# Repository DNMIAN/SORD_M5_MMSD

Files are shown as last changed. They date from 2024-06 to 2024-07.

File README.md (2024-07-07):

SORD m5 メモリマッパー (+SD)  
  
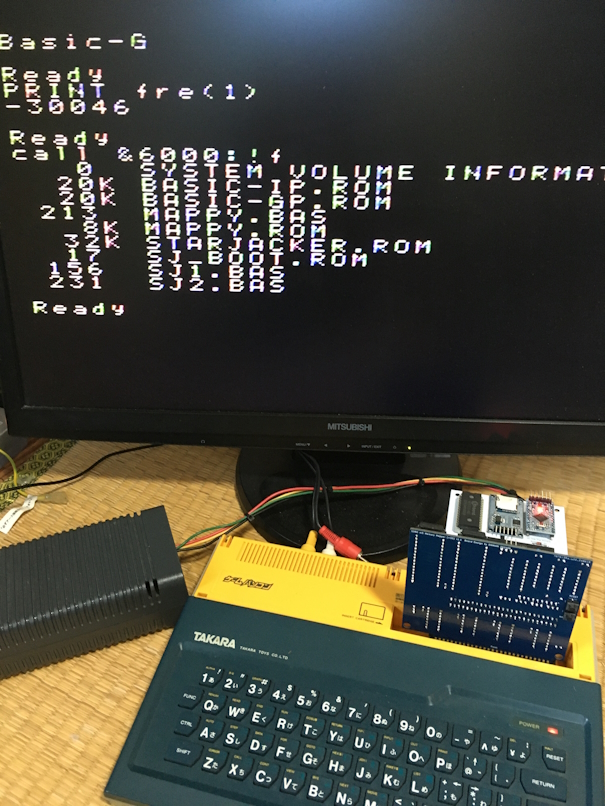
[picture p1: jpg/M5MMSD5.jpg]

  
注意  
・m5 Jr.に挿せるかは検証できていません。  
・純正電源で動作するかは確認できていません。（外部電源入力は可能）  

1. 概要  
  
本ハードウェアは、SORD m5（および互換PC）に、ROMを512Kバイト、RAMを512Kバイトを拡張する装置です。  
各メモリは16Kバイト単位のセグメントに分割され、ROM32ページ、RAM32ページとして管理します。  
CPUのメモリ空間64Kバイトを16Kバイト単位で4分割し、CPU空間0～3とします。  
それぞれのCPU空間について、任意のページを対応させることができます。  
（いわゆるMSXのメモリマッパーです）  
  
また、yanatakaさんのMSX_SD ver1.6 (https://github.com/yanataka60/MSX_SD) を使用することを目的とした、  
MSXカートリッジI/F（以降、MSX-I/F)を備えています。  

2. 製作について  
  
組み立て以外に、EPROM書き込みが必要です。  
  
また、MSX_SDのドキュメントも必ず読みましょう。  
MSX_SDはArduinoスケッチ書き込みが必要です。  

3. 基板、部品リスト  
  
回路図とガーバーデータはKiCad7.0で作成しています。  
  
動作確認をした部品リストを、以下に示します。  
74HCをLSにした場合、動作しない可能性があります。  
  
U1,U2 : 74LS670 x2  
U3 : 74HC244  
U4 : HM628512ALP-7  
U5 : 512Kx8bit以下 DIP32 EPROM（M27C4001-10F1,W27C010-70で確認）  
U6 : 74HC20  
U7 : 74HC00  
U8 : 74HC30  
U9 : 74HC139  
CON : カードエッジコネクタ 2x25P 2.54mm  
C1～C9 : 積層セラミックコンデンサ 50V 0.1uF x9  
C10 : 電解コンデンサ 16V 100uF  
RN1 : 集合抵抗 6素子 10kΩ  
R1 : 抵抗 10kΩ  
SW1,SW2 : タクトスイッチ TVDP17-050B-D x2  
EX5V : ピンヘッダ 1x2P 2.54mm  
EX12V,GND : ピンヘッダ 1x3P 2.54mm  
EXIO,A4～A7 : ピンヘッダ 1x3P 2.54mm x5  
ICソケット : DIP32（U5用）  
ジャンパーピン : 2.54mm（EX5V,EXIO,A4～A7用） x6  
  
MSX_SD ver1.6 : 基板は公開されているガーバーから作成  
U1 : 74HC02  
U2 : 74HC138  
U3 : W27C512-45Z（後半32KBを使用） ※MSXで動作確認時に使用  
U4 : uPD8255AC-5  
U5 : Arduino Pro Mini 328 5V 16MHz（ピンヘッダ付属）  
J3 : MicroSD Card Adapter  
C1～C4 : 積層セラミックコンデンサ 50V 0.1uF x4  
C5 : 電解コンデンサ 16V 100uF  
D1 : ダイオード 1N4148  
ピンヘッダ : 1x2P 2.54mm（Arduino A4,A5用）  
ICソケット : DIP28（U3用）  
microSDカード : 2GB  
  
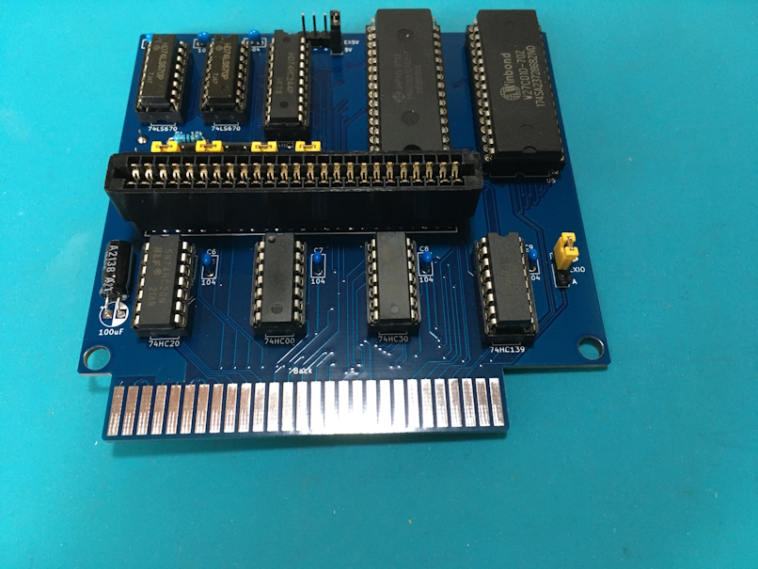
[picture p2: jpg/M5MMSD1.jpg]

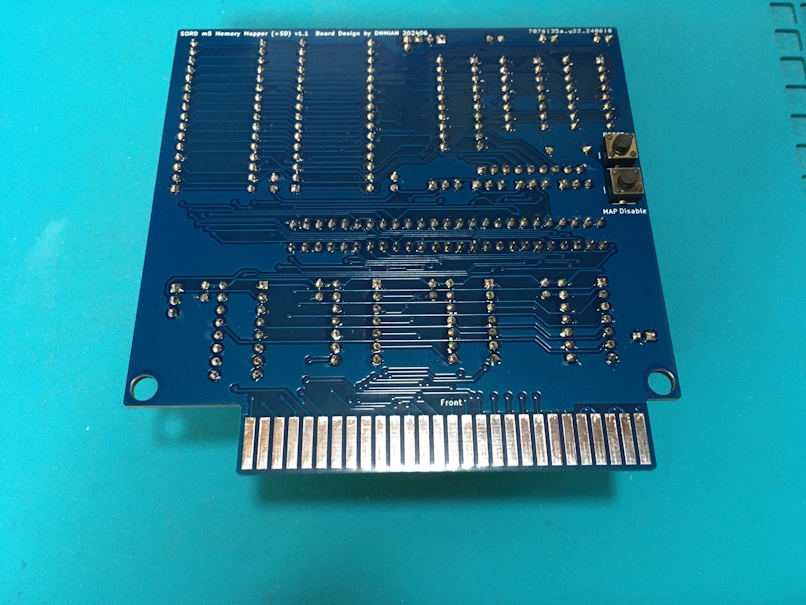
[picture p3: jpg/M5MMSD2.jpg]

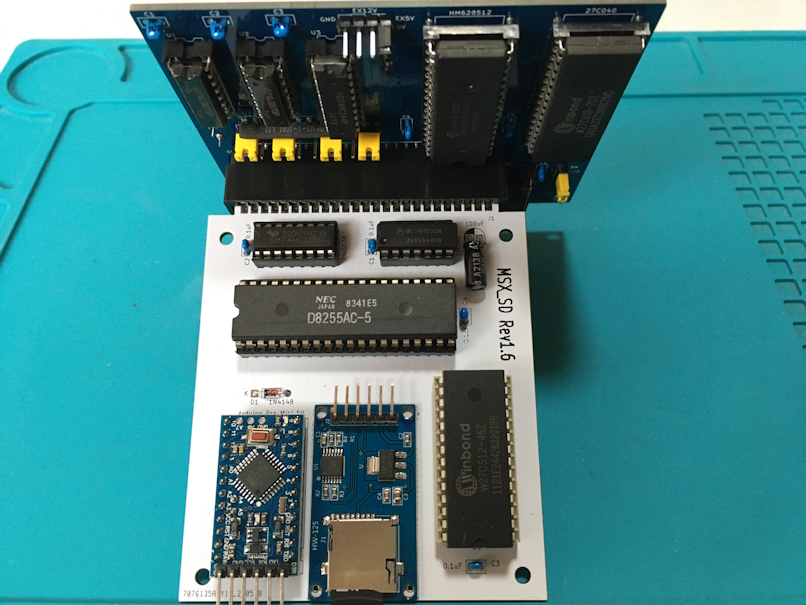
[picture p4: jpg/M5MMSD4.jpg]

  
4. ジャンパー設定  
  
基板上にあるジャンパーついての説明です。  
EXIO,A4～A7ジャンパーは●側をショート、EX5V-5Vもショートしてください。（計6箇所）  
  
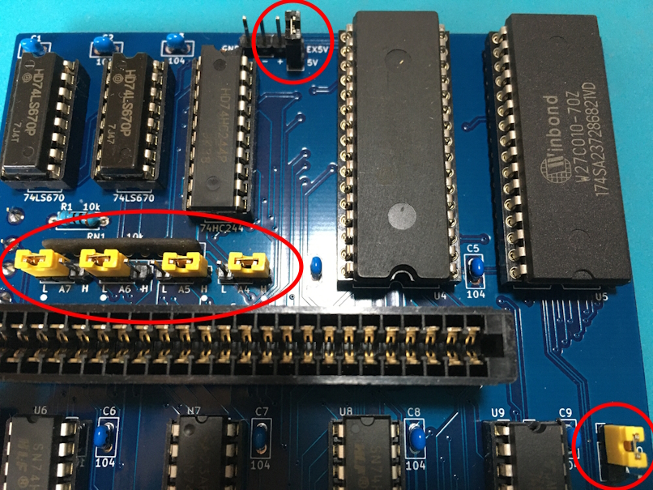
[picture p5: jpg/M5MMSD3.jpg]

  
EXIO : MSX-I/Fの/IORQを、選択（/EXIOA or /EXIOB）します。m5は7xHを使用するので/EXIOBを設定します。  
A4～A7 : アドレスバスA4～A7を選択します（H or L）、これは使用するMSXカートリッジの仕様に強制的に合わせるものです。MSX_SDのIOポートは、38H～3BHなので、A7L, A6L, A5H, A4Hを設定します。  
EX5V : MSX-I/Fの5V供給を選択します。5Vとショートでm5から供給です。外部供給する場合、ジャンパーを外して、EX5V側へ5Vを接続します。  
5V : m5供給の5Vです。  
EX12V : MSX_SDでは使用しません。ジャンパーはしないでください。MSX-I/Fに±12Vが必要な場合は、それぞれのピンから外部供給できます。  
GND : 外部供給時のGNDを接続します。  
  
m5カートリッジバスの/IORQは、6xHアクセスで/EXIOA、7xHアクセスで/EXIOBがアサートされます。  
アドレスをそのままMSX-I/Fに出力した場合、MSXカートリッジは60H～7FHまでのIO機器しか使用できません。  
MSX_SDは38H～3BHを使用します。  
上位4bitを3(0011b)に固定することで、m5での78Hアクセスを、MSX-I/Fでは38Hアクセスに見せかけます。  
  
この仕組みを使用して、他のIOカートリッジを動作させることができるかもしれません。  
（MSX-MUSICの7CH,7DHを、6CH,6DHでアクセスするなど（メモリマッパー7CH～7FHとの競合回避））  

5. Arduinoスケッチについて  
  
MSXM5_SD.inoファイルを使用してください。  
MSX_SD.inoにm5処理を追加しているので、そのままMSXでも動作します。  

6. ROMについて  
  
メモリマッパーに実装するROMは、4Mbit(M27C4001, AM27C040, W27E040など), 2Mbit, 1Mbit等の  
32ピンDIPパッケージが使用可能です。（容量が少ない場合は、サイズ毎にページ内容がミラーされます）  
  
MSX_SD上のROMは使用しません。m5のみで使用なら実装する必要はありません。  

7. マッパーセグメントの切替について  
  
CPU空間0～3の対応は、マッパーセグメント選択レジスタによって決められます。  
マッパーセグメント選択レジスタは、I/Oアドレスの7CH番地から7FH番地までの4バイトです。  
レジスタ値は00H～1FHでROM, 20H～3FHでRAMを選択します。  
  
電源投入後の初期値は、全レジスタ値ともに不定のため、マッパーセグメント選択レジスタに書き込むまでは  
強制的に無効（全レジスタ値=00H扱い）する機能を実装しています。  
このため、ROMの0ページに適切な初期化処理を配置するのが良いでしょう。  
  
また、m5のハードウェア制約により、ページ0の0000H～1FFFHはIPLROM、ページ1の7000～7FFFHは内蔵RAMに固定されます。  
  
m5のブートシーケンスは、詳細は書きませんが、起動時に2000Hから 02 xx yy zz vv のコードがあれば、vvzzを呼び出します。  
vvzzから復帰後、yyxxを呼び出しますが、復帰しないプログラムならyyxxを設定する必要はありません。  
  
よって、ページ0の2000Hからマッパー初期化処理を配置することになります。  
しかし、実行中のコードがあるページを切り替えると、コードがすり替わってしまい想定外の動作となるため、  
別ページで切替処理を実行する必要があります。  
  
電源投入時は全ページ0となっているため、2000Hからのコードは、6000H, A000H, E000Hでもアクセスすることができます。  
これを利用して、例えばAxxxHへ分岐して、そこでページ0のマッパー設定を行うと良いように見えますが、これは間違いです。  
  
前述にある「強制的に無効」する機能は、マッパーレジスタに書き込みを行うことで、解除されます。  
よって、解除された瞬間に、不定レジスタ値でページが切り替わってしまう可能性があります。  
これを回避するため、最初はページ0のレジスタ値を0に更新します。  
その後、ページ1,2,3のレジスタ値についても適切に更新しておくのが良いでしょう。  
  
なお、「強制的に無効」する機能は、リセットでは有効になりません。  
マッパーレジスタ値も、リセットでは変化しません。  
「強制的に無効」する機能を有効にしたい（＝ページ0から実行）場合は、ボード上の「MAP Disable」ボタンを一度押してください。  
押した瞬間に動作しますので、その後、RESETボタンも押して再起動するのが良いでしょう。  
電源投入時は、（ほぼ）有効になると思いますが、起動しない場合は「MAP Disable」＋「RESET」を試して見ましょう。  

8. MSX_SD上のSDアクセスについて  
  
ハード的な仕様はオリジナルのままです。  
MSX_SDで使うSDカードは8GB以下が望ましいとの記載がありました。  
  
SDアクセス（＋マッパー切替）については、BASIC-I,BASIC-G用の簡易プログラムを作りました。  
（yanatakaさんのPC-8001_SDを参考にしています。）  
使い方は、ソースコードの先頭にあるコメントを参照してください。  
なお、SD読み書き時のエラーチェックはしていません、容量不足などには注意ください。  

9. プログラムとか  
  
MSXM5_SD.ino : MSX_SDのArduinoスケッチ  
  
EXT_ROM_M5.s : SDアクセス（＋マッパー切替） ソースコード  
EXT_ROM_M5_G.ROM : BASIC-G用のRAWファイル（6000H～6FFFHへ実装用）  
EXT_ROM_M5_I.ROM : BASIC-I用のRAWファイル（6000H～6FFFHへ実装用）  
  
BOOT_SAMPLE.s : ブート サンプルソースコード  
BOOT_SAMPLE.rom : RAWファイル（2000H～2FFFHへ実装用）  
  
BOOT_SEL.s : ブートセレクターソースコード  
BOOT_SEL.rom : RAWファイル（2000H～2FFFHへ実装用）  

10. ライセンスとか  
  
This project is licensed under the MIT License, see the LICENSE.txt file for details

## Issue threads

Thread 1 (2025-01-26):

how to launch game ?

hpx1984, 2025-01-26:
hi Sir

thx your great project , i love it and like to build one
now im already completed MSX_SD and it can working on MSX

based to review the details of this project im still not know how to launch game
i saw from video many times
my question
1. what format for the M5 ROM what can be launch ? .rom or .bas?(I find some M5 ROM but it is .bin format )
2. what file need to stock in sd card ?and how to place these file?
3. what command for launch game ?

for the PCB
seems move the Connector to another side then not need to remove the M5 Card cover for use MMSD

DNMIAN, 2025-01-26:
First, you need a BOOT ROM to insert into U5.
If you use BOOT_SEL.rom, you can load the file on the SD and start it.
Since the U5 ROM runs from 2000H, leave 0000 to 1FFFH blank and place BOOT_SEL.rom from 2000H.
The file to be placed in the SD is a binary that can be executed from 2000H. This is a raw dump of a ROM cartridge.
Also, regarding BASIC programs, I don't think you can use anything other than those saved with M5MMSD.
When loading and saving to SD in BASIC, the corresponding EXT_ROM_M5 must be placed in 6000H.
In the case of BASIC-G, it is 16KB, just concatenate EXT_ROM_M5_G.rom after the ROM image and make it into one file.
In the case of BASIC-I, it is 8KB, so concatenate an 8KB blank at the end, and concatenate EXT_ROM_M5_I.rom after that to make one file.
Thank you.

hpx1984, 2025-01-26:
Many thx your explained Sir DNMIAN

Now i got to know some details about M5-MMSD ,but im new guy on M5 and BASIC, so still some information that i can't understand at this moment
I think need to build and complete one M5-MMSD board then can study and try how to use it
I will go ahead to order M5-MMSD PCB and Elec components

So might need more help from you later

DNMIAN, 2025-01-27:
I hope that you can complete it.
Please let me know if you have any questions.
Good luck.

DNMIAN, 2025-02-24:
Thank you for assembling.

M5-MMSD Board:
Write the M5-MMSD/Z80/Work/BOOT_SEL_0000H.rom to W27C010-70.
This is BOOT_SEL.rom with 2kbytes of free space inserted at the beginning.

MSX-SD board ROM chip
Since this ROM is not used, a program for MSX is fine.

The boot selector should now start.

Please try it.

hpx1984, 2025-02-24:
last week end i already trial to use BOOT_SEL.rom to do some modification by HxD tool to insert FF to 0x0000-0x1FFF and then move the original code start at 0x2000 and then repack the ROM to program into 27c010 but got black screen and click some key can get key tone

Now im just trial to use Work/BOOT_SEL_0000H.rom to W27C010-70 and got same status as above

hpx1984, 2025-02-24:
what files need to put into TF card ?
is it the problem why i got black screen ?
because no correct files put into TF card

DNMIAN, 2025-02-25:
Just to confirm, it's hard to see the image, but is the EXIO jumper set to B?

If it stops at a black screen, I think it's because it hasn't started or the MSX-SD can't be initialized.
First, you should see a list of files. You can check it with the TF card of MSX-SD. The file can be anything.

First, let's check if it works on its own.
Don't have BASIC-I,G or game ROM image?
Create an empty 8kbytes file and concatenate the BASIC or game ROM image to the back.
(ROM image start is 0x2000)
Write it to W27C010 and boot with it.
Do not insert MSX-SD.

DNMIAN, 2025-02-25:
sorry. I'm posting a mistake. Please wait while I correct it.

DNMIAN, 2025-02-25:
Write the M5-MMSD/Z80/Work/TEST.ROM to W27C010-70.

hpx1984, 2025-02-26:
HI Sir

TEST.ROM and insert MSX-SD without SD card=black screen
TEST.ROM without MSX-SD=black screen

DNMIAN, 2025-02-26:
Write the M5-MMSD/Z80/Work/BOOT_TEST.ROM to W27C010-70.
There is no need to insert MSX-SD.

If nothing is displayed on the screen even after this, can you run it using an external power supply?

Remove the EX5V-5V jumper and connect an external power supply of about 5V1A between EX5V and GND.

DNMIAN, 2025-02-26:
If the screen does not appear, try pressing the "MAP Disable" + "RESET" buttons while the power is on.

hpx1984, 2025-02-28:
Hi Sir

BOOT_TEST.ROM to W27C010-70=black screen
Remove the EX5V-5V jumper and connect an external power supply of about 5V1A between EX5V and GND=black screen
pressing the "MAP Disable" + "RESET" buttons while the power is on and then release these two bottons=black screen

hpx1984, 2025-02-28:
Hi Sir

BOOT_TEST.ROM to W27C010-70=black screen
Remove the EX5V-5V jumper and connect an external power supply of about 5V1A between EX5V and GND=black screen
pressing the "MAP Disable" + "RESET" buttons while the power is on and then release these two bottons=black screen

DNMIAN, 2025-03-02:
Regular BASIC and game cartridges work, right?
Also, you haven't modified the m5 body, right?
If this doesn't work, all I can think of is that the IC isn't working or there's a wiring mistake somewhere.

I'm sorry that I can't seem to solve it.

Operation result with BOOT_TEST.ROM
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

hpx1984, 2025-03-02:
Hi Sir

the original BASIC-G and Game cartridges can working
i never modify my M5

i bought 5 sets IC before , let me try to replace them and double check the soldering status to looking if any mistake

hpx1984, 2025-03-08:
Hi Sir

Could you show which chip you are use for reference ? then i will try to find the same one to try again

This is what chip i used

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

DNMIAN, 2025-03-09:
The one I'm using is as shown in the picture, the RAM is remarked (it disappeared when I rubbed it, it's fake). I think it was the same as the one in the second picture.

Since it is a socket, operation can be checked with minimal implementation.
Remove HC30, LS670x2, and HM628512, and set W27C010 to BOOT_TEST.ROM.
Now when you boot up, BOOT TEST will be displayed. If the screen goes blank immediately and a relay sound is heard, press MAPdisable and then RESET.
Now BOOT TEST will be displayed.
First, let's aim to get this to work.

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

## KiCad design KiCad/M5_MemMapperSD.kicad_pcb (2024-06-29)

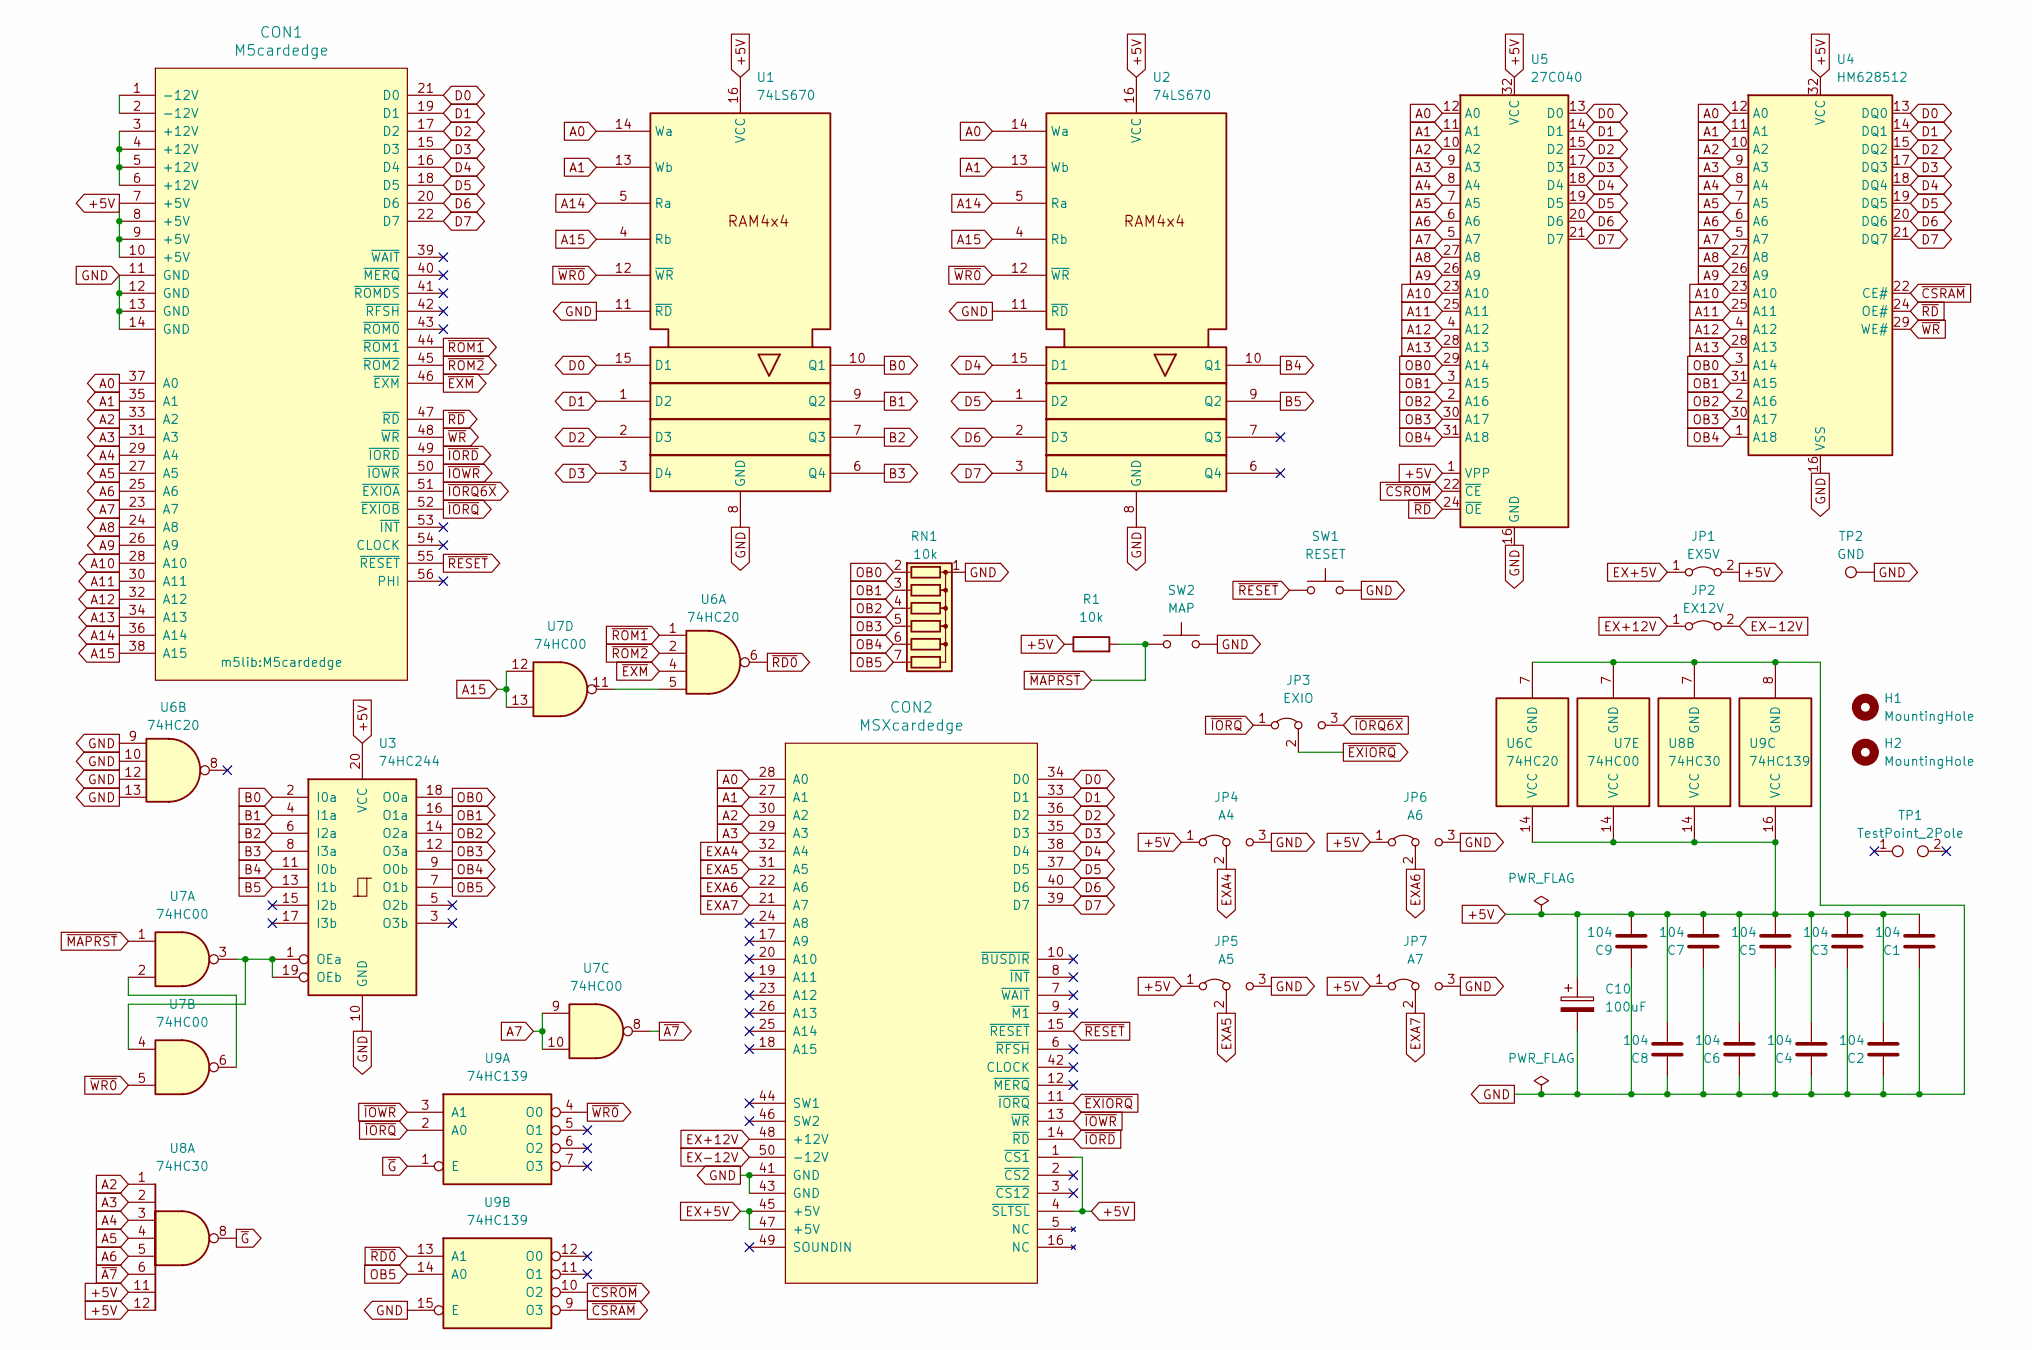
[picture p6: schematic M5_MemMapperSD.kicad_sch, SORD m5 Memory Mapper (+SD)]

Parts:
C1, C2, C3, C4, C5, C6, C7, C8, C9: 104; C_Disc_D5.0mm_W2.5mm_P2.50mm
C10: 100uF; CP_Radial_D5.0mm_P2.50mm
CON1: M5cardedge
CON2: MSXcardedge; 50_pin_edge_female
H1, H2: MountingHole; MountingHole_4.5mm
JP1: EX5V; PinHeader_1x02_P2.54mm_Vertical
JP2: EX12V; PinHeader_1x02_P2.54mm_Vertical
JP3: EXIO; PinHeader_1x03_P2.54mm_Vertical
JP4: A4; PinHeader_1x03_P2.54mm_Vertical
JP5: A5; PinHeader_1x03_P2.54mm_Vertical
JP6: A6; PinHeader_1x03_P2.54mm_Vertical
JP7: A7; PinHeader_1x03_P2.54mm_Vertical
R1: 10k; R_Axial_DIN0207_L6.3mm_D2.5mm_P7.62mm_Horizontal
RN1: 10k; R_Array_SIP7
SW1: RESET; SW_PUSH_6mm_H4.3mm_2pin
SW2: MAP; SW_PUSH_6mm_H4.3mm_2pin
TP1: TestPoint_2Pole; C_Disc_D5.0mm_W2.5mm_P2.50mm
TP2: GND; TestPoint_THTPad_2.0x2.0mm_Drill1.0mm
U1, U2: 74LS670; DIP-16_W7.62mm
U3: 74HC244; DIP-20_W7.62mm
U4: HM628512; DIP-32_W15.24mm
U5: 27C040; DIP-32_W15.24mm
U6: 74HC20; DIP-14_W7.62mm
U7: 74HC00; DIP-14_W7.62mm
U8: 74HC30; DIP-14_W7.62mm
U9: 74HC139; DIP-16_W7.62mm

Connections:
+5V: C1.2, C2.2, C3.2, C4.2, C5.2, C6.2, C7.2, C8.2, C9.2, C10.1, CON1.7 (+5V), CON1.8 (+5V), CON1.9 (+5V), CON1.10 (+5V), CON2.1 (~CS1), CON2.4 (~SLTSL), JP1.2 (B), JP4.1 (A), JP5.1 (A), JP6.1 (A), JP7.1 (A), R1.1, U1.16 (VCC), U2.16 (VCC), U3.20 (VCC), U4.32 (VCC), U5.1 (VPP), U5.32 (VCC), U6.14 (VCC), U7.14 (VCC), U8.11, U8.12, U8.14 (VCC), U9.16 (VCC)
A0: CON1.37 (A0), CON2.28 (A0), U1.14 (Wa), U2.14 (Wa), U4.12 (A0), U5.12 (A0)
A1: CON1.35 (A1), CON2.27 (A1), U1.13 (Wb), U2.13 (Wb), U4.11 (A1), U5.11 (A1)
A2: CON1.33 (A2), CON2.30 (A2), U4.10 (A2), U5.10 (A2), U8.1
A3: CON1.31 (A3), CON2.29 (A3), U4.9 (A3), U5.9 (A3), U8.2
A4: CON1.29 (A4), U4.8 (A4), U5.8 (A4), U8.3
A5: CON1.27 (A5), U4.7 (A5), U5.7 (A5), U8.4
A6: CON1.25 (A6), U4.6 (A6), U5.6 (A6), U8.5
A7: CON1.23 (A7), U4.5 (A7), U5.5 (A7), U7.9, U7.10
A8: CON1.24 (A8), U4.27 (A8), U5.27 (A8)
A9: CON1.26 (A9), U4.26 (A9), U5.26 (A9)
A10: CON1.28 (A10), U4.23 (A10), U5.23 (A10)
A11: CON1.30 (A11), U4.25 (A11), U5.25 (A11)
A12: CON1.32 (A12), U4.4 (A12), U5.4 (A12)
A13: CON1.34 (A13), U4.28 (A13), U5.28 (A13)
A14: CON1.36 (A14), U1.5 (Ra), U2.5 (Ra)
A15: CON1.38 (A15), U1.4 (Rb), U2.4 (Rb), U7.12, U7.13
B0: U1.10 (Q1), U3.2 (I0a)
B1: U1.9 (Q2), U3.4 (I1a)
B2: U1.7 (Q3), U3.6 (I2a)
B3: U1.6 (Q4), U3.8 (I3a)
B4: U2.10 (Q1), U3.11 (I0b)
B5: U2.9 (Q2), U3.13 (I1b)
D0: CON1.21 (D0), CON2.34 (D0), U1.15 (D1), U4.13 (DQ0), U5.13 (D0)
D1: CON1.19 (D1), CON2.33 (D1), U1.1 (D2), U4.14 (DQ1), U5.14 (D1)
D2: CON1.17 (D2), CON2.36 (D2), U1.2 (D3), U4.15 (DQ2), U5.15 (D2)
D3: CON1.15 (D3), CON2.35 (D3), U1.3 (D4), U4.17 (DQ3), U5.17 (D3)
D4: CON1.16 (D4), CON2.38 (D4), U2.15 (D1), U4.18 (DQ4), U5.18 (D4)
D5: CON1.18 (D5), CON2.37 (D5), U2.1 (D2), U4.19 (DQ5), U5.19 (D5)
D6: CON1.20 (D6), CON2.40 (D6), U2.2 (D3), U4.20 (DQ6), U5.20 (D6)
D7: CON1.22 (D7), CON2.39 (D7), U2.3 (D4), U4.21 (DQ7), U5.21 (D7)
EX+5V: CON2.45 (+5V), CON2.47 (+5V), JP1.1 (A)
EX+12V: CON2.48 (+12V), JP2.1 (A)
EX-12V: CON2.50 (-12V), JP2.2 (B)
EXA4: CON2.32 (A4), JP4.2 (C)
EXA5: CON2.31 (A5), JP5.2 (C)
EXA6: CON2.22 (A6), JP6.2 (C)
EXA7: CON2.21 (A7), JP7.2 (C)
unnamed: CON1.3 (+12V), CON1.4 (+12V), CON1.5 (+12V), CON1.6 (+12V)
unnamed: CON1.1 (-12V), CON1.2 (-12V)
unnamed: U3.1 (OEa), U3.19 (OEb), U7.3, U7.4
unnamed: U6.5, U7.11
unnamed: U7.2, U7.6
OB0: RN1.2 (R1), U3.18 (O0a), U4.3 (A14), U5.29 (A14)
OB1: RN1.3 (R2), U3.16 (O1a), U4.31 (A15), U5.3 (A15)
OB2: RN1.4 (R3), U3.14 (O2a), U4.2 (A16), U5.2 (A16)
OB3: RN1.5 (R4), U3.12 (O3a), U4.30 (A17), U5.30 (A17)
OB4: RN1.6 (R5), U3.9 (O0b), U4.1 (A18), U5.31 (A18)
OB5: RN1.7 (R6), U3.7 (O1b), U9.14 (A0)
~A7: U7.8, U8.6
~CSRAM: U4.22 (CE#), U9.9 (O3)
~CSROM: U5.22 (~CE), U9.10 (O2)
~EXIORQ: CON2.11 (~IORQ), JP3.2 (C)
~EXM: CON1.46 (~EXM), U6.4
~G: U8.8, U9.1 (E)
~IORD: CON1.49 (~IORD), CON2.14 (~RD)
~IORQ6X: CON1.51 (~EXIOA), JP3.3 (B)
~IORQ: CON1.52 (~EXIOB), JP3.1 (A), U9.2 (A0)
~IOWR: CON1.50 (~IOWR), CON2.13 (~WR), U9.3 (A1)
~RD0: U6.6, U9.13 (A1)
~RD: CON1.47 (~RD), U4.24 (OE#), U5.24 (~OE)
~ROM1: CON1.44 (~ROM1), U6.1
~ROM2: CON1.45 (~ROM2), U6.2
~WR0: U1.12 (~WR), U2.12 (~WR), U7.5, U9.4 (O0)
~WR: CON1.48 (~WR), U4.29 (WE#)

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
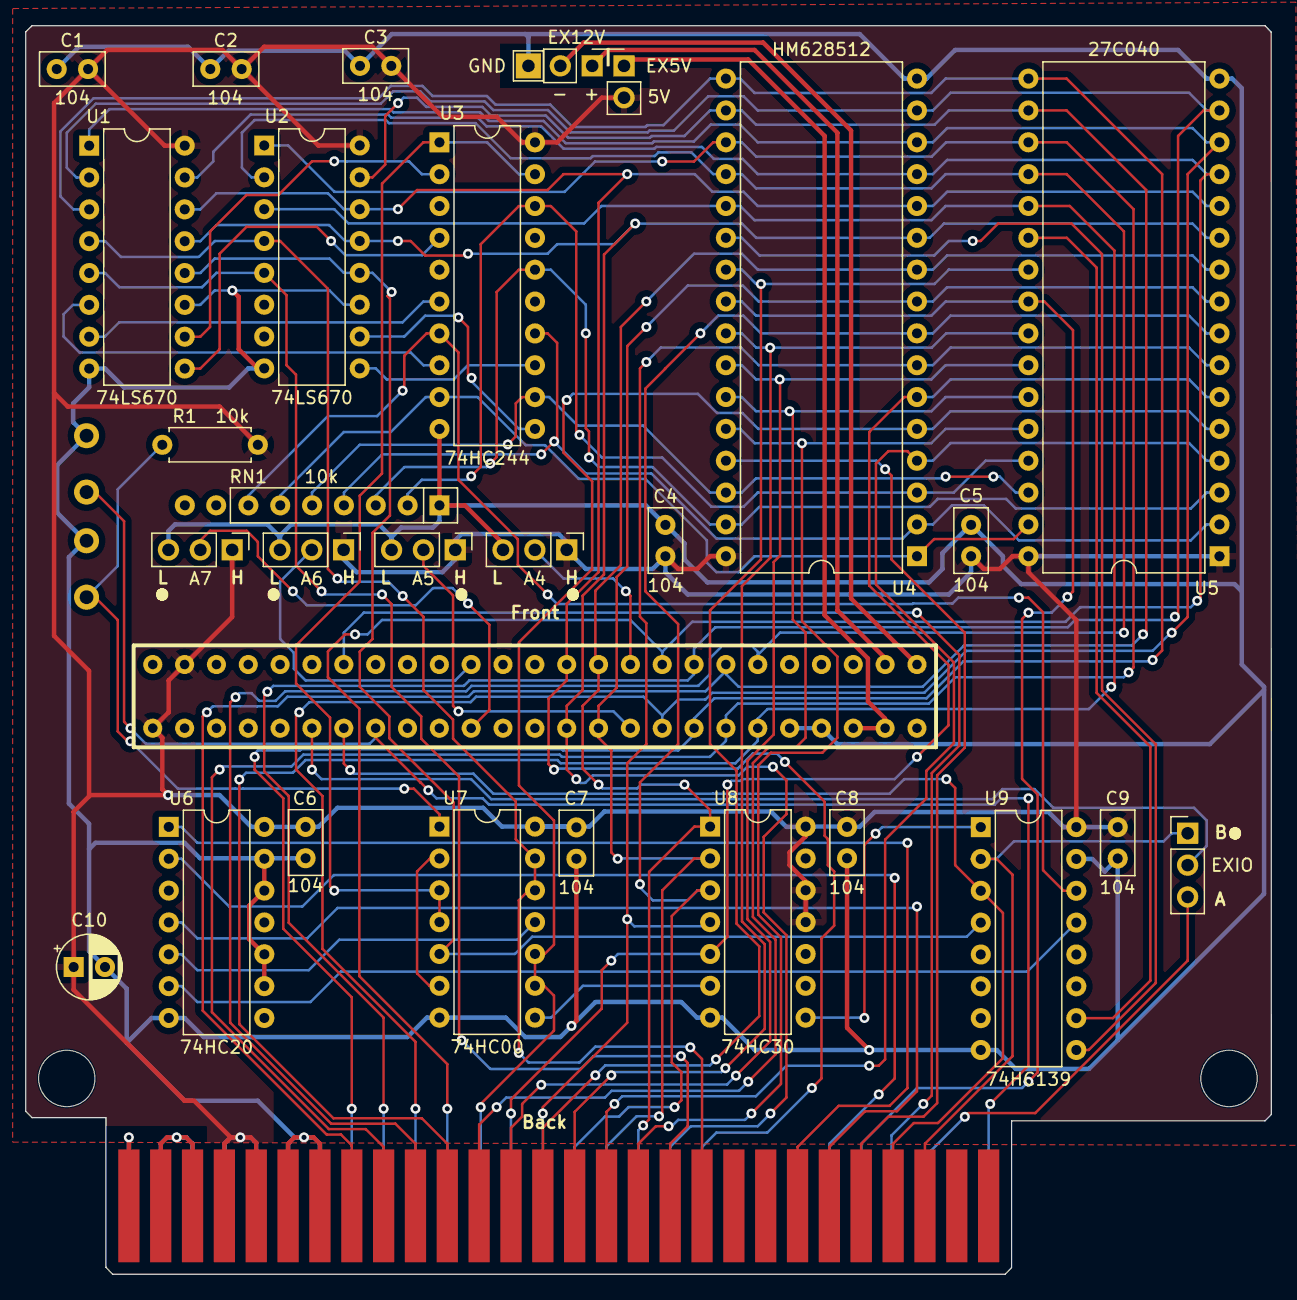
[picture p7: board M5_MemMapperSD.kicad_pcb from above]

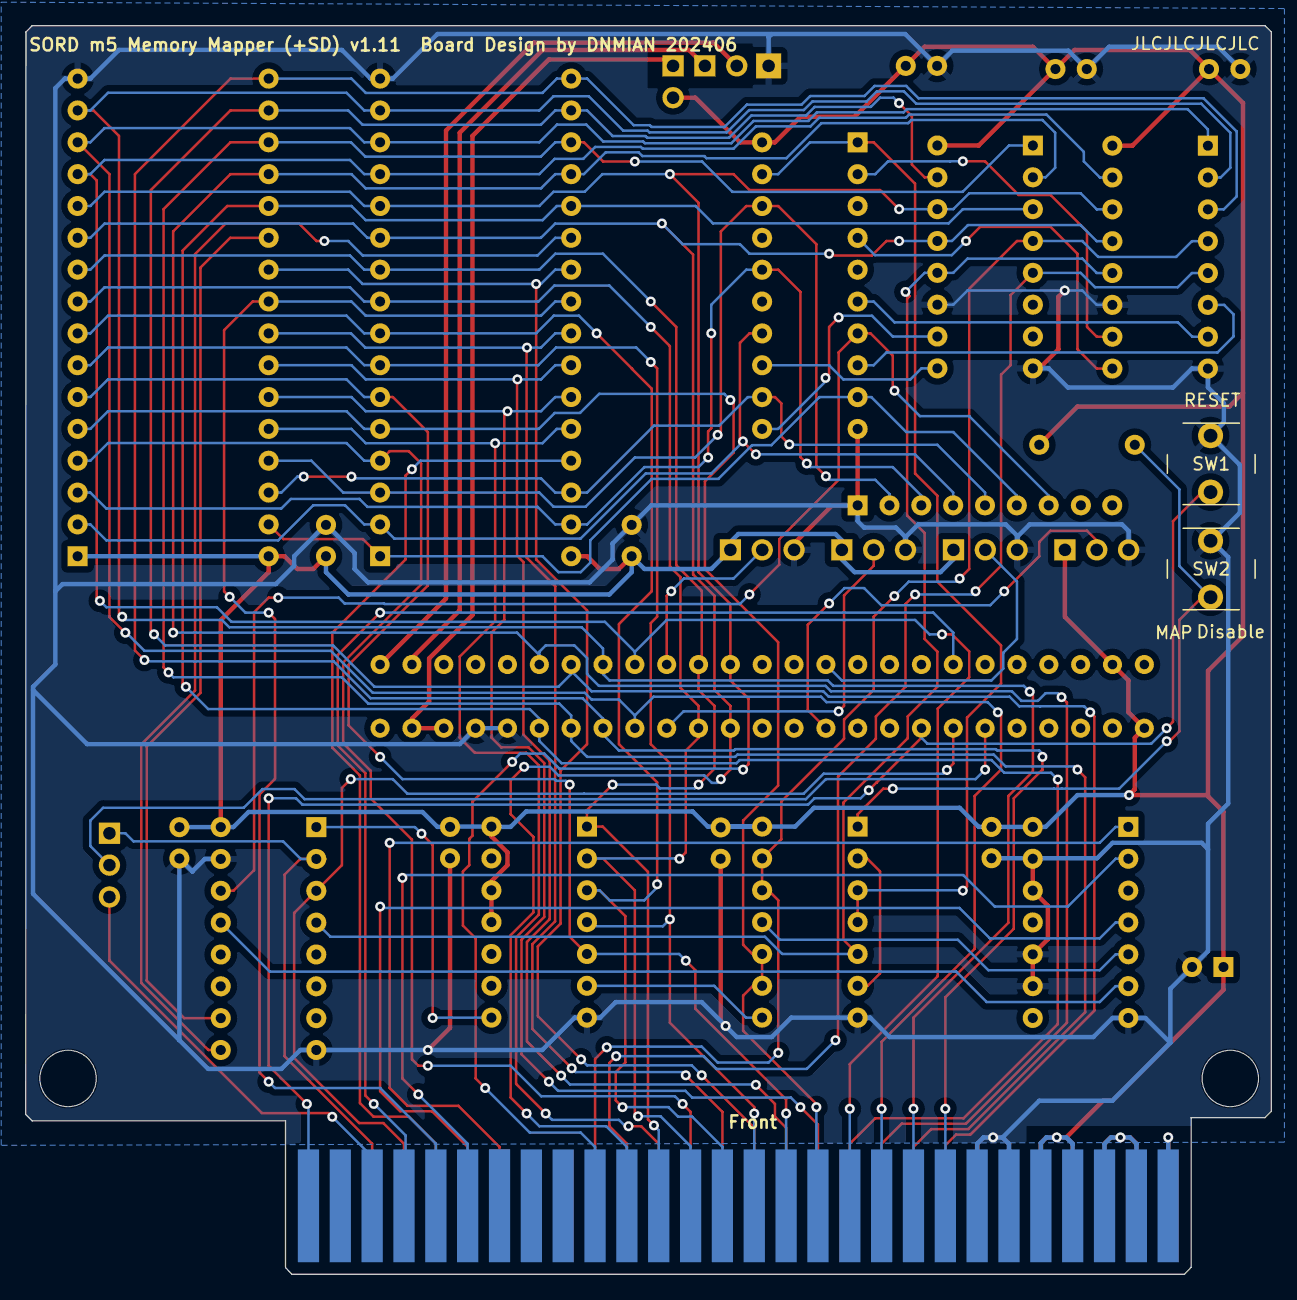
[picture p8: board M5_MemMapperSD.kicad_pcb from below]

Board: 2 copper layers, 99.4 x 99.6 mm, 36 parts (2 on the bottom side), 68 nets.

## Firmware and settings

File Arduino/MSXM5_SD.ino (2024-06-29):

//2024. 3.13 sd-card再挿入時の初期化処理を追加
//2024. 6.10 m5用処理（PC-8001ベース）を追加
//
#include "SdFat.h"
#include <SPI.h>
SdFat SD;
unsigned long r_count=0;
unsigned long f_length=0, w_length=0;
char m_name[40];
char f_name[40];
char w_name[40];
char c_name[40];
char sdir[10][40];
File file_r,file_w;
unsigned int s_adrs,e_adrs,g_adrs,s_adrs1,s_adrs2;
int s_len1,s_len2,w_len1,w_len2;
boolean eflg;

#define CABLESELECTPIN  (10)
#define CHKPIN          (15)
#define PB0PIN          (2)
#define PB1PIN          (3)
#define PB2PIN          (4)
#define PB3PIN          (5)
#define PB4PIN          (6)
#define PB5PIN          (7)
#define PB6PIN          (8)
#define PB7PIN          (9)
#define FLGPIN          (14)
#define PA0PIN          (16)
#define PA1PIN          (17)
#define PA2PIN          (18)
#define PA3PIN          (19)
// ファイル名は、ロングファイルネーム形式対応

void sdinit(void){
  // SD初期化
  if( !SD.begin(CABLESELECTPIN,8) )
  {
////    Serial.println("Failed : SD.begin");
    eflg = true;
  } else {
////    Serial.println("OK : SD.begin");
    eflg = false;
  }
////    Serial.println("START");
}

void setup(){
////    Serial.begin(9600);
// CS=pin10
// pin10 output

  pinMode(CABLESELECTPIN,OUTPUT);
  pinMode( CHKPIN,INPUT);  //CHK
  pinMode( PB0PIN,OUTPUT); //送信データ
  pinMode( PB1PIN,OUTPUT); //送信データ
  pinMode( PB2PIN,OUTPUT); //送信データ
  pinMode( PB3PIN,OUTPUT); //送信データ
  pinMode( PB4PIN,OUTPUT); //送信データ
  pinMode( PB5PIN,OUTPUT); //送信データ
  pinMode( PB6PIN,OUTPUT); //送信データ
  pinMode( PB7PIN,OUTPUT); //送信データ
  pinMode( FLGPIN,OUTPUT); //FLG

  pinMode( PA0PIN,INPUT_PULLUP); //受信データ
  pinMode( PA1PIN,INPUT_PULLUP); //受信データ
  pinMode( PA2PIN,INPUT_PULLUP); //受信データ
  pinMode( PA3PIN,INPUT_PULLUP); //受信データ

  digitalWrite(PB0PIN,LOW);
  digitalWrite(PB1PIN,LOW);
  digitalWrite(PB2PIN,LOW);
  digitalWrite(PB3PIN,LOW);
  digitalWrite(PB4PIN,LOW);
  digitalWrite(PB5PIN,LOW);
  digitalWrite(PB6PIN,LOW);
  digitalWrite(PB7PIN,LOW);
  digitalWrite(FLGPIN,LOW);

  delay(500);

//SETSコマンドでSAVE用ファイル名を指定なくSAVEされた場合のデフォルトファイル名を設定
  strcpy(w_name,"default.cas");

  sdinit();
}

//4BIT受信
byte rcv4bit(void){
//HIGHになるまでループ
  while(digitalRead(CHKPIN) != HIGH){
  }
//受信
  byte j_data = digitalRead(PA0PIN)+digitalRead(PA1PIN)*2+digitalRead(PA2PIN)*4+digitalRead(PA3PIN)*8;
//FLGをセット
  digitalWrite(FLGPIN,HIGH);
//LOWになるまでループ
  while(digitalRead(CHKPIN) == HIGH){
  }
//FLGをリセット
  digitalWrite(FLGPIN,LOW);
  return(j_data);
}

//1BYTE受信
byte rcv1byte(void){
  byte i_data = 0;
  i_data=rcv4bit()*16;
  i_data=i_data+rcv4bit();
  return(i_data);
}

//1BYTE送信
void snd1byte(byte i_data){
//下位ビットから8ビット分をセット
  digitalWrite(PB0PIN,(i_data)&0x01);
  digitalWrite(PB1PIN,(i_data>>1)&0x01);
  digitalWrite(PB2PIN,(i_data>>2)&0x01);
  digitalWrite(PB3PIN,(i_data>>3)&0x01);
  digitalWrite(PB4PIN,(i_data>>4)&0x01);
  digitalWrite(PB5PIN,(i_data>>5)&0x01);
  digitalWrite(PB6PIN,(i_data>>6)&0x01);
  digitalWrite(PB7PIN,(i_data>>7)&0x01);
  digitalWrite(FLGPIN,HIGH);
//HIGHになるまでループ
  while(digitalRead(CHKPIN) != HIGH){
  }
  digitalWrite(FLGPIN,LOW);
//LOWになるまでループ
  while(digitalRead(CHKPIN) == HIGH){
  }
}

//小文字->大文字
char upper(char c){
  if('a' <= c && c <= 'z'){
    c = c - ('a' - 'A');
  }
  return c;
}

//ファイル名の最後が「.cas」でなければ付加
void addcas(char *f_name,char *m_name){
  unsigned int lp1=0;
  while (f_name[lp1] != 0x00){
    m_name[lp1] = f_name[lp1];
    lp1++;
  }
  if (f_name[lp1-4]!='.' ||
    ( f_name[lp1-3]!='c' &&
      f_name[lp1-3]!='C' ) ||
    ( f_name[lp1-2]!='a'  &&
      f_name[lp1-3]!='A' ) ||
    ( f_name[lp1-1]!='s' &&
      f_name[lp1-1]!='S' ) ){
         m_name[lp1++] = '.';
         m_name[lp1++] = 'c';
         m_name[lp1++] = 'a';
         m_name[lp1++] = 's';
  }
  m_name[lp1] = 0x00;
}

//比較文字列取得 32+1文字まで取得、ただしダブルコーテーションは無視する
void receive_name(char *f_name){
char r_data;
  unsigned int lp2 = 0;
  for (unsigned int lp1 = 0;lp1 <= 32;lp1++){
    r_data = rcv1byte();
    if (r_data != 0x22){
      f_name[lp2] = r_data;
      lp2++;
    }
  }
}

//比較文字列取得 32+1文字まで取得し先頭の6文字をファイルネームとする、ただしダブルコーテーションは無視する
void receive_name6(char *f_name){
char r_data;
  unsigned int lp2 = 0;
  for (unsigned int lp1 = 0;lp1 <= 32;lp1++){
    r_data = rcv1byte();
    if (lp2 < 6){
      if (r_data != 0x22){
        f_name[lp2] = r_data;
        lp2++;
      }
    }else{
      f_name[lp2] = 0x00;
      lp2++;
    }
  }
}

//f_nameとc_nameをc_nameに0x00が出るまで比較
//FILENAME COMPARE
boolean f_match(char *f_name,char *c_name){
  boolean flg1 = true;
  unsigned int lp1 = 0;
  while (lp1 <=32 && c_name[0] != 0x00 && flg1 == true){
    if (upper(f_name[lp1]) != c_name[lp1]){
      flg1 = false;
    }
    lp1++;
    if (c_name[lp1]==0x00){
      break;
    }
  }
  return flg1;
}

// SD-CARDのFILELIST
void dirlist(void){
//比較文字列取得 32+1文字まで
  receive_name(c_name);
//
  File file2 = SD.open( "/" );
  if( file2 == true ){
//状態コード送信(OK)
    snd1byte(0x00);

    File entry =  file2.openNextFile();
    int cntl2 = 0;
    unsigned int br_chk =0;
    int page = 1;
//全件出力の場合には10件出力したところで一時停止、キー入力により継続、打ち切りを選択
    while (br_chk == 0) {
      if(entry){
        entry.getName(f_name,36);
        unsigned int lp1=0;
//一件送信
//比較文字列でファイルネームを先頭から比較して一致するものだけを出力
        if (f_match(f_name,c_name)){
//sdir[]にf_nameを保存
          strcpy(sdir[cntl2],f_name);
          snd1byte(0x30+cntl2);
          snd1byte(0x20);
          while (lp1<=36 && f_name[lp1]!=0x00){
          snd1byte(upper(f_name[lp1]));
          lp1++;
          }
          snd1byte(0x0D);
          snd1byte(0x00);
          cntl2++;
        }
      }
// CNTL2 > 表示件数-1
      if (!entry || cntl2 > 9){
//継続・打ち切り選択指示要求
        snd1byte(0xfe);

//選択指示受信(0:継続 B:前ページ 以外:打ち切り)
        br_chk = rcv1byte();
//前ページ処理
        if (br_chk==0x42){
//先頭ファイルへ
          file2.rewindDirectory();
//entry値更新
          entry =  file2.openNextFile();
//もう一度先頭ファイルへ
          file2.rewindDirectory();
          if(page <= 2){
//現在ページが1ページ又は2ページなら1ページ目に戻る処理
            page = 0;
          } else {
//現在ページが3ページ以降なら前々ページまでのファイルを読み飛ばす
            page = page -2;
            cntl2=0;
//page*表示件数
            while(cntl2 < page*10){
              entry =  file2.openNextFile();
              if (f_match(f_name,c_name)){
                cntl2++;
              }
            }
          }
          br_chk=0;
        }
//1～0までの数字キーが押されたらsdir[]から該当するファイル名を送信
        if(br_chk>=0x30 && br_chk<=0x39){
          file_r = SD.open( sdir[br_chk-0x30], FILE_READ );
          if( file_r == true ){
//f_length設定、r_count初期化
            f_length = file_r.size();
            r_count = 0;
            unsigned int lp2=0;
            snd1byte(0xFD);
            while (lp2<=36 && sdir[br_chk-0x30][lp2]!=0x00){
              snd1byte(upper(sdir[br_chk-0x30][lp2]));
              lp2++;
            }
            snd1byte(0x0A);
            snd1byte(0x0D);
            snd1byte(0x00);
          }
        }
        page++;
        cntl2 = 0;
      }
//ファイルがまだあるなら次読み込み、なければ打ち切り指示
      if (entry){
        entry =  file2.openNextFile();
      }else{
        br_chk=1;
      }
    }
//処理終了指示
    snd1byte(0xFF);
    snd1byte(0x00);
  }else{
    snd1byte(0xf1);
  }
}

// LOADFILEOPEN 読み込み用のファイル名を設定する
void loadopen(void){
  boolean flg = false;
//DOSファイル名取得
  receive_name(m_name);
  addcas(m_name,f_name);
//ファイルが存在しなければERROR
  if (SD.exists(f_name) == true){
//ファイルオープン
    file_r = SD.open( f_name, FILE_READ );

    if( true == file_r ){
//f_length設定、r_count初期化
      f_length = file_r.size();
      r_count = 0;
//状態コード送信(OK)
      snd1byte(0x00);
      flg = true;
    } else {
      snd1byte(0xf2);
      sdinit();
      flg = false;
    }
  }else{
    snd1byte(0xf1);
    sdinit();
    flg = false;
  }
}

// SAVEFILEOPEN 書き込み用のファイル名を設定する
void saveopen(void){
  boolean flg = false;
//DOSファイル名取得
  receive_name(m_name);
  addcas(m_name,f_name);
  strcpy(w_name,f_name);
//ファイルオープン
  if(file_w==true){
    file_w.close();
  }
  file_w = SD.open( w_name, FILE_WRITE );
//状態コード送信(OK)
  snd1byte(0x00);
}

// sloadコマンド
void sload(void){
  boolean flg = false;
  int wk1 =0;
  unsigned char rdata;
  unsigned int lp1 =0;
//比較文字列取得 32+1文字まで
  receive_name6(c_name);
  if (file_r == true){
    snd1byte(0x00);
//0xd3が10個連続するまで読み飛ばし、読み飛ばしでファイルエンドになってしまったらエラー終了
    while (flg == false && f_length >= r_count){
      rdata=file_r.read();
      r_count++;
      if (rdata == 0xd3){
          wk1++;
        } else{
          wk1=0;
      }
      if (wk1 >= 10 ){
        flg = true;
      }
//ファイルネームが指定された場合、読み出したファイルネームが一致するまで読み飛ばし
      if (flg == true){
        for(lp1=0; lp1 <= 5;lp1++){
          f_name[lp1]=file_r.read();
          r_count++;
        }
        f_name[6]=0x00;
        if (c_name[0]!=0x00){
          if (f_match(f_name,c_name) == false){
            flg = false;
          }
        }
      }
    }
    if(flg == true){
      snd1byte(0x00);
//ファイルネームを送信
      for(lp1=0; lp1 <= 5;lp1++){
        snd1byte(f_name[lp1]);
      }
//ヘッダを読み飛ばし
      for(lp1=1; lp1 <= 8;lp1++){
        rdata=file_r.read();
        r_count++;
      }
//次行アドレスポインタから1行Byte数を計算し送信、1行Byte数分の実データも読み出して送信
      s_adrs2=file_r.read();
      r_count++;
      s_adrs1=file_r.read();
      r_count++;
      e_adrs = s_adrs1*256+s_adrs2;
      if (e_adrs != 0){
        wk1=s_adrs2-3;
        snd1byte(wk1);
        s_adrs =e_adrs;
        for (lp1=1;lp1 <= wk1;lp1++){
          rdata=file_r.read();
          r_count++;
          snd1byte(rdata);
        }
      }
//2行目以降処理
//次行アドレスポインタから1行Byte数を計算し送信、1行Byte数分の実データも読み出して送信
      while (e_adrs != 0){
        s_adrs2=file_r.read();
        r_count++;
        s_adrs1=file_r.read();
        r_count++;
        e_adrs = s_adrs1*256+s_adrs2;
        if (e_adrs != 0){
          wk1 = e_adrs-s_adrs-2;
          s_adrs =e_adrs;
          snd1byte(wk1);
          for (lp1=1;lp1 <= wk1;lp1++){
            rdata=file_r.read();
            r_count++;
            snd1byte(rdata);
          }
        }
      }
      snd1byte(0x00);
    } else{
      snd1byte(0xf1);
      sdinit();
      r_count = 0;
    }
  } else{
    snd1byte(0xf1);
    sdinit();
    r_count = 0;
  }
}

// sbloadコマンド
void sbload(void){
  boolean flg = false;
  int wk1 =0;
  unsigned char rdata;
  unsigned int lp1 =0;
//比較文字列取得 32+1文字まで
  receive_name6(c_name);
  if (file_r == true){
    snd1byte(0x00);
//0xd0を10個連続するまで読み飛ばし、読み飛ばしでファイルエンドになってしまったらエラー終了
    while (flg == false && f_length >= r_count){
      rdata=file_r.read();
      r_count++;
      if (rdata == 0xd0){
          wk1++;
        } else{
          wk1=0;
      }
      if (wk1 >= 10 ){
        flg = true;
      }
//ファイルネームが指定された場合、読み出したファイルネームが一致するまで読み飛ばし
      if (flg == true){
        for(lp1=0; lp1 <= 5;lp1++){
          f_name[lp1]=file_r.read();
          r_count++;
        }
        f_name[6]=0x00;
        if (c_name[0]!=0x00){
          if (f_match(f_name,c_name) == false){
            flg = false;
          }
        }
      }
    }
    if(flg == true){
      snd1byte(0x00);
//ファイルネームを送信
      for(lp1=0; lp1 <= 5;lp1++){
        snd1byte(f_name[lp1]);
      }
//ヘッダを読み飛ばし
      for(lp1=1; lp1 <= 8;lp1++){
        rdata=file_r.read();
        r_count++;
      }
//スタートアドレスを読み出して送信
      s_adrs2=file_r.read();
      r_count++;
      s_adrs1=file_r.read();
      r_count++;
      s_adrs = s_adrs1*256+s_adrs2;
      snd1byte(s_adrs2);
      snd1byte(s_adrs1);
//エンドアドレスを読み出して送信
      s_adrs2=file_r.read();
      r_count++;
      s_adrs1=file_r.read();
      r_count++;
      e_adrs = s_adrs1*256+s_adrs2;
      snd1byte(s_adrs2);
      snd1byte(s_adrs1);
//実行アドレスを読み出して送信
      s_adrs2=file_r.read();
      r_count++;
      s_adrs1=file_r.read();
      r_count++;
      g_adrs = s_adrs1*256+s_adrs2;
      snd1byte(s_adrs2);
      snd1byte(s_adrs1);
//スタートアドレスからエンドアドレスまでのデータを読み出して送信
      for(lp1=s_adrs; lp1 <= e_adrs;lp1++){
        rdata=file_r.read();
        snd1byte(rdata);
        r_count++;
      }
    } else{
      snd1byte(0xf1);
      sdinit();
      r_count = 0;
    }
  } else{
    snd1byte(0xf1);
    sdinit();
    r_count = 0;
  }
}

//ヘッダ書き込み
void header_write(void){
        file_w.write(char(0x1f));
        file_w.write(char(0xa6));
        file_w.write(char(0xde));
        file_w.write(char(0xba));
        file_w.write(char(0xcc));
        file_w.write(char(0x13));
        file_w.write(char(0x7d));
        file_w.write(char(0x74));
}

//ファイルヘッダ書き込み
void file_header(char hdata){
  unsigned int lp1 =0;
//ロングヘッダ書き込み
  header_write();
//hdata x 10
  for(lp1=1; lp1 <= 10;lp1++){
    file_w.write(hdata);
  }
//ファイルネーム送信及び書き込み
  for(lp1=0; lp1 <= 5;lp1++){
    snd1byte(c_name[lp1]);
    file_w.write(c_name[lp1]);
  }
//ショートヘッダ書き込み
      header_write();
}

// ssaveコマンド
void ssave(void){
  boolean flg = false;
  unsigned int wk1 =0;
  unsigned char rdata;
  unsigned int lp1 =0;
//比較文字列取得 32+1文字まで
  receive_name6(c_name);
//ファイルネームが指定されていなければエラー
  if (c_name[0] != 0x00){
//w_nameでファイルオープン
    if(file_w==true){
      file_w.close();
    }
    file_w = SD.open( w_name, FILE_WRITE );
    if(file_w==true){
      snd1byte(0x00);
//ファイルヘッダ書き込み
      file_header(char(0xd3));
      wk1=rcv1byte();
//1行Byte数が0になるまでループ
      while(wk1!=0){
//次行プログラムポインタを受信して書き込み
        rdata=rcv1byte();
        file_w.write(rdata);
        rdata=rcv1byte();
        file_w.write(rdata);
//1行分のデータを受信して書き込み
          for(lp1=1; lp1 <= wk1;lp1++){
            rdata=rcv1byte();
            file_w.write(rdata);
          }
        wk1=rcv1byte();
      }
//終了マークを書き込み
      for(lp1=1; lp1 <= 12;lp1++){
        file_w.write(char(0x00));
      }
      file_w.close();
      snd1byte(0x00);
    }else{
      snd1byte(0xf1);
      sdinit();
    }
  }else{
    snd1byte(0xf1);
    sdinit();
  }
}  

// sbsaveコマンド
void sbsave(void){
  boolean flg = false;
  unsigned int wk1 =0;
  unsigned char rdata;
  unsigned int lp1 =0;
//比較文字列取得 32+1文字まで
  receive_name6(c_name);
//パラメータ正常フラグが送られてきたら処理継続
  rdata = rcv1byte();
  if (rdata == 0x00){
//ファイルネームが指定されていなければエラー終了
    if (c_name[0] != 0x00){
//w_nameでファイルオープン
      if(file_w==true){
        file_w.close();
      }
      file_w = SD.open( w_name, FILE_WRITE );
      if(file_w==true){
        snd1byte(0x00);
//ファイルヘッダ書き込み
      file_header(char(0xd0));
//スタートアドレス受信及び書き込み
        s_adrs1=rcv1byte();
        file_w.write(s_adrs1);
        s_adrs2=rcv1byte();
        file_w.write(s_adrs2);
        s_adrs = s_adrs2*256+s_adrs1;
//エンドアドレス受信及び書き込み
        s_adrs1=rcv1byte();
        file_w.write(s_adrs1);
        s_adrs2=rcv1byte();
        file_w.write(s_adrs2);
        e_adrs = s_adrs2*256+s_adrs1;
//実行アドレス受信及び書き込み
        s_adrs1=rcv1byte();
        file_w.write(s_adrs1);
        s_adrs2=rcv1byte();
        file_w.write(s_adrs2);
        g_adrs = s_adrs2*256+s_adrs1;
//スタートアドレスからエンドアドレスまでのデータを受信して書き込み
        for(lp1=0; lp1 <= (e_adrs-s_adrs);lp1++){
          rdata=rcv1byte();
          file_w.write(rdata);
        }
        file_w.close();
        snd1byte(0x00);
      }else{
        snd1byte(0xf1);
        sdinit();
      }
    }else{
      snd1byte(0xf1);
      sdinit();
    }
  }
}

void loop()
{
  digitalWrite(PB0PIN,LOW);
  digitalWrite(PB1PIN,LOW);
  digitalWrite(PB2PIN,LOW);
  digitalWrite(PB3PIN,LOW);
  digitalWrite(PB4PIN,LOW);
  digitalWrite(PB5PIN,LOW);
  digitalWrite(PB6PIN,LOW);
  digitalWrite(PB7PIN,LOW);
  digitalWrite(FLGPIN,LOW);
//コマンド取得待ち
////    Serial.println("COMMAND WAIT");
  byte cmd = rcv1byte();
////    Serial.println(cmd,HEX);
  if (eflg == false){
    switch(cmd) {
//41hでファイルリスト出力
      case 0x41:
////    Serial.println("FILE LIST START");
//状態コード送信(OK)
        snd1byte(0x00);
        sdinit();
        dirlist();
        break;
//42hでLOADFILEOPEN
      case 0x42:
////    Serial.println("LOADFILEOPEN");
//状態コード送信(OK)
        snd1byte(0x00);
        loadopen();
        break;
//43hでSAVEFILEOPEN
      case 0x43:
////    Serial.println("SAVEFILEOPEN");
//状態コード送信(OK)
        snd1byte(0x00);
        saveopen();
        break;
//44h:sload
      case 0x44:
////    Serial.println("sload START");
//状態コード送信(OK)
        snd1byte(0x00);
        sload();
////  delay(1500);
        break;
//45h:sbload
      case 0x45:
////    Serial.println("sbload START");
//状態コード送信(OK)
        snd1byte(0x00);
        sbload();
////  delay(1500);
        break;
//46h:ssave
      case 0x46:
////    Serial.println("ssave START");
//状態コード送信(OK)
        snd1byte(0x00);
        ssave();
////  delay(1500);
        break;
//47h:sbsave
      case 0x47:
////    Serial.println("sbsave START");
//状態コード送信(OK)
        snd1byte(0x00);
        sbsave();
////  delay(1500);
        break;

//70h:m5 BIN SAVE
      case 0x70:
////    Serial.println("m5 BIN SAVE START");
//状態コード送信(OK)
        snd1byte(0x00);
        m5_bin_save();
        break;
//71h:m5 BIN LOAD
      case 0x71:
////    Serial.println("m5 BIN LOAD START");
//状態コード送信(OK)
        snd1byte(0x00);
        m5_bin_load();
        break;
//72h:m5 RAW LOAD
      case 0x72:
////    Serial.println("m5 RAW LOAD START");
//状態コード送信(OK)
        snd1byte(0x00);
        m5_raw_load();
        break;
//73h:m5 BASIC LOAD
      case 0x73:
////    Serial.println("m5 BASIC LOAD START");
//状態コード送信(OK)
        snd1byte(0x00);
        m5_bas_load();
        break;
//74h:m5 BASIC SAVE
      case 0x74:
////    Serial.println("m5 BASIC SAVE START");
//状態コード送信(OK)
        snd1byte(0x00);
        m5_bas_save();
        break;
//75h:m5 KILL
      case 0x75:
////    Serial.println("m5 KILL START");
//状態コード送信(OK)
        snd1byte(0x00);
        m5_kill();
        break;
//76h:m5 NAME
      case 0x76:
////    Serial.println("m5 NAME START");
//状態コード送信(OK)
        snd1byte(0x00);
        m5_name();
        break;
//77h:m5 COPY
      case 0x77:
////    Serial.println("m5 COPY START");
//状態コード送信(OK)
        snd1byte(0x00);
        m5_copy();
        break;
//83hでファイルリスト出力(m5)
      case 0x83:
////    Serial.println("m5 FILE LIST START");
//状態コード送信(OK)
        snd1byte(0x00);
        sdinit();
        m5_dirlist();
        break;
//84h:m5 CHK
      case 0x84:
////    Serial.println("m5 CHK START");
//状態コード送信(OK)
        snd1byte(0x00);
        break;	

      default:
//状態コード送信(CMD ERROR)
        snd1byte(0xF4);
    }
  } else {
//状態コード送信(ERROR)
    snd1byte(0xF0);
    sdinit();
  }
}

//(m5)BASICプログラムのLOAD処理
void m5_bas_load(void){
  boolean flg = false;
  unsigned char rdata;
//DOSファイル名取得
  receive_name(f_name);
//ファイル名の指定が無ければエラー
  if (f_name[0]!=0x00){

//ファイルが存在しなければERROR
    if (SD.exists(f_name) == true){
//ファイルオープン
      file_r = SD.open( f_name, FILE_READ );

      if( true == file_r ){
//f_length設定
        f_length = file_r.size();
        if ( f_length < 10 ){
          snd1byte(0xf2);
          sdinit();
          flg = false;
        }
//状態コード送信(OK)
        snd1byte(0x00);
        flg = true;
      } else {
        snd1byte(0xf0);
        sdinit();
        flg = false;
      }
    }else{
      snd1byte(0xf1);
      sdinit();
      flg = false;
    }
  }else{
    snd1byte(0xf3);
    flg = false;
  }

//良ければファイルエンドまで読み込みを続行する
  if (flg == true) {
    int rdata = 0;
      
//ヘッダー読み込み
    rdata = file_r.read();
    f_length--;
//ヘッダー送信
    snd1byte(rdata);

//ヘッダーが0xd3なら続行、違えばエラー
    if (rdata == 0xd3){

//ブロック数、端数算出
      s_len1 = f_length / 255;
      s_len2 = f_length % 255;

//実データ送信
//0xFFブロック
      while (s_len1 > 0){

//データ長を送信
        snd1byte(0xff);

        for (unsigned int lp1 = 1;lp1 <= 255;lp1++){
//実データを読み込んで送信
          rdata = file_r.read();
          snd1byte(rdata);
        }
        s_len1--;
      }

//データ長を送信
      snd1byte(s_len2);

//端数ブロック処理
      if (s_len2 > 0){
        for (unsigned int lp1 = 1;lp1 <= s_len2;lp1++){
//実データを読み込んで送信
          rdata = file_r.read();
          snd1byte(rdata);
        }
        snd1byte(0x00);
      }
    }
    file_r.close();
  }
}

//(m5)BASICプログラムのSAVE処理
void m5_bas_save(void){
unsigned int lp1;

//DOSファイル名取得
  receive_name(f_name);
//ファイル名の指定が無ければエラー
  if (f_name[0]!=0x00){

//オープン中のファイルがあればクローズ（無いと思うけど）
    if( true == file_w ){
      file_w.close();
    }
  
//ファイルが存在すればdelete
    if (SD.exists(f_name) == true){
      SD.remove(f_name);
    }
//ファイルオープン
    file_w = SD.open( f_name, FILE_WRITE );
    if( true == file_w ){
//状態コード送信(OK)
      snd1byte(0x00);

//スタートアドレス取得
      s_adrs1 = rcv1byte();
      s_adrs2 = rcv1byte();
//スタートアドレス算出
      s_adrs = s_adrs1+s_adrs2*256;
//エンドアドレス取得
      s_adrs1 = rcv1byte();
      s_adrs2 = rcv1byte();
//エンドアドレス算出
      e_adrs = s_adrs1+s_adrs2*256;
//ヘッダー 0xD3書き込み
      file_w.write(char(0xD3));
//実データ (e_adrs - s_adrs +1)を受信、書き込み
      for (lp1 = s_adrs;lp1 <= e_adrs;lp1++){
        file_w.write(rcv1byte());
      }
      file_w.close();
    } else {
      snd1byte(0xf0);
      sdinit();
    }
  }else{
    snd1byte(0xf3);
  }
}

//(m5)KILL処理
void m5_kill(void){

//DOSファイル名取得
  receive_name(f_name);
//ファイル名の指定が無ければエラー
  if (f_name[0]!=0x00){
  
//状態コード送信(OK)
      snd1byte(0x00);
//ファイルが存在すればdelete
    if (SD.exists(f_name) == true){
      SD.remove(f_name);
//状態コード送信(OK)
      snd1byte(0x00);
    }else{
      snd1byte(0xf1);
      sdinit();
    }
  }else{
    snd1byte(0xf3);
  }
}

//(m5)NAME処理
void m5_name(void){

//DOSファイル名1取得
  receive_name(f_name);
//ファイル名1の指定が無ければエラー
  if (f_name[0]!=0x00){
  
//状態コード送信(OK)
    snd1byte(0x00);

//DOSファイル名2取得
    receive_name(w_name);
//ファイル名2の指定が無ければエラー
    if (w_name[0]!=0x00){

//状態コード送信(OK)
      snd1byte(0x00);

//ファイル1が存在すればrename
      if (SD.exists(f_name) == true){

//ファイル2が存在すればエラー
        if (SD.exists(w_name) == false){

          SD.rename(f_name,w_name);

//状態コード送信(OK)
          snd1byte(0x00);
        }else{
          snd1byte(0xf4);
          sdinit();
        }
      }else{
        snd1byte(0xf5);
        sdinit();
      }
    }else{
      snd1byte(0xf3);
      sdinit();
    }
  }else{
    snd1byte(0xf3);
  }
}


//(m5)COPY処理
void m5_copy(void){

  unsigned int lp1;
  unsigned char bufdata[256];
//DOSファイル名1取得
  receive_name(f_name);
//ファイル名1の指定が無ければエラー
  if (f_name[0]!=0x00){
  
//状態コード送信(OK)
    snd1byte(0x00);
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
